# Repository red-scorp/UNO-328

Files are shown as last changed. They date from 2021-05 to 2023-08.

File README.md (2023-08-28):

# UNO/328 project

UNO/328 is a clone board of popular Arduino Uno board.
Main goal of the project is to improve EMC property of original board keeping it still simple and cheap to produce.

## Uno_v1.0

**Uno_v1.0** is version 1.0 of the board featuring CH340G USB to UART chip and ATMEGA328P as MCU.

Preview:

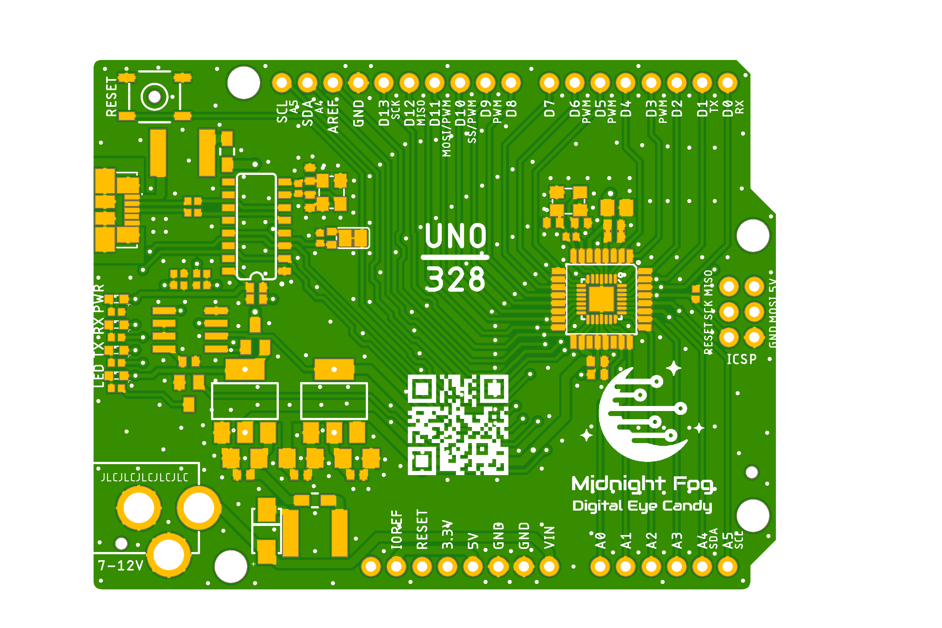
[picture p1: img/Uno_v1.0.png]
Uno_v1.0 preview


[Schematics in PDF format](doc/Uno_v1.0.pdf)

Features:

- Uno compatible board pinout
- Uno compatible MCU ATMEGA328P
- 2 layer board design
- alternative footprints for MCU: TQFP and HVQFN
- CH340G chip as USB to UART bridge
- modern microUSB connector
- possibly better EMC parameters (not yet tested)

CAM files are available.
BoM and PnP files for JLCPCB are available.

## Links

- CH340G Driver for Windows: [CH341SER_ZIP](http://www.wch.cn/download/CH341SER_ZIP.html)

## How to help

Your contributions as code, resources, or finances are welcome! Please contact me directly via email at andriy.golovnya@gmail.com or through my [GitHub profile](https://github.com/red-scorp).

If you'd like to make a financial contribution, you can donate via [PayPal](http://paypal.me/redscorp) or [Ko-Fi](http://ko-fi.com/redscorp). Your support is greatly appreciated.

Thanks in advance!

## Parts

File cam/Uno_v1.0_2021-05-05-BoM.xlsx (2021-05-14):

Qty | Designator | Footprint | Comment | LCSC Part # | Description
3 | C1, C2, C3 | 1206 | 47uF | C96123 (https://lcsc.com/product-detail/Multilayer-Ceramic-Capacitors-MLCC-SMD-SMT_SAMSUNG_CL31A476MPHNNNE_47uF-476-20-10V_C96123.html/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) | CAPACITOR, European symbol
1 | C17 | 0805 | 10uF | C15850 (https://lcsc.com/product-detail/Multilayer-Ceramic-Capacitors-MLCC-SMD-SMT_SAMSUNG_CL21A106KAYNNNE_10uF-106-10-25V_C15850.html/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) | CAPACITOR, European symbol
11 | C4, C5, C6, C7, C8, C11, C14, C15, C16, C18, C19 | 0402 | 100nF | C1525 (https://lcsc.com/product-detail/Multilayer-Ceramic-Capacitors-MLCC-SMD-SMT_SAMSUNG_CL05B104KO5NNNC_100nF-104-10-16V_C1525.html/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) | CAPACITOR, European symbol
4 | C9, C10, C12, C13 | 0402 | 12pF | C1547 (https://lcsc.com/product-detail/Multilayer-Ceramic-Capacitors-MLCC-SMD-SMT_12pF-120-5-50V_C1547.html/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) | CAPACITOR, European symbol
1 | D1 | SMA,DO-214AC | M7 | C366566 (https://lcsc.com/product-detail/Others_DOWO-M7_C366566.html/?href=jlc-SMT) | WE-TVSP Power TVS Diode
2 | F1, F2 | 1812 | 1812L050/30PR | C151168 (https://lcsc.com/product-detail/PTC-Resettable-Fuses_Littelfuse-1812L050-30PR_C151168.html/?href=jlc-SMT) | MF-SMDF Series - PRC Resettable Fuses
1 | IC1 | SOT-223 | AMS1117-5.0 | C6187 (https://lcsc.com/product-detail/Low-Dropout-Regulators-LDO_AMS_AMS1117-5-0_AMS1117-5-0_C6187.html/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) | Low drop fixed and adjustable positive voltage regulators 1 A
1 | IC2 | SOT-223 | AMS1117-3.3 | C6186 (https://lcsc.com/product-detail/Low-Dropout-Regulators-LDO_AMS_AMS1117-3-3_AMS1117-3-3_C6186.html/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) | Low drop fixed and adjustable positive voltage regulators 1 A
1 | IC3 | SOIC-8_3.9x4.9x1.27P | LM358DR2G | C7950 (https://lcsc.com/product-detail/General-Purpose-Amplifiers_ON-Semicon_LM358DR2G_ON-Semicon-ON-LM358DR2G_C7950.html/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) | OpAmp
2 | L1, L2 | 0805 | GZ2012D601TF | C1017 (https://lcsc.com/product-detail/Beads_Sunlord-GZ2012D601TF_C1017.html/?href=jlc-SMT) | WE-CBA SMD EMI Suppression Ferrite Bead
1 | LED1 | LED_0603 | GREEN | C72043 (https://lcsc.com/product-detail/Light-Emitting-Diodes-LED_0603-Green-light_C72043.html/?href=jlc-SMT) | LED
2 | LED2, LED3 | LED_0603 | BLUE | C72041 (https://lcsc.com/product-detail/Light-Emitting-Diodes-LED_0603-Blue-light_C72041.html/?href=jlc-SMT) | LED
1 | LED4 | LED_0603 | YELLOW | C72038 (https://lcsc.com/product-detail/Light-Emitting-Diodes-LED_0603-Yellow-light_C72038.html/?href=jlc-SMT) | LED
1 | Q1 | SMD-3225_4P | 12MHz | C9002 (https://lcsc.com/product-detail/SMD-Crystal-Resonators_Yangxing-Tech-X322512MSB4SI_C9002.html/?href=jlc-SMT) | Quartz Crystals (MHz) SMD:
1 | Q2 | SMD-3225_4P | 16MHz | C13738 (https://lcsc.com/product-detail/SMD-Crystal-Resonators_Yangxing-Tech-X322516MLB4SI_C13738.html/?href=jlc-SMT) | Quartz Crystals (MHz) SMD:
2 | R1, R2 | 0402 | 22R | C25092 (https://lcsc.com/product-detail/Chip-Resistor-Surface-Mount_Uniroyal-Elec-0402WGF220JTCE_C25092.html/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) | RESISTOR, European symbol
1 | R12 | 0402 | 10K | C25744 (https://lcsc.com/product-detail/Chip-Resistor-Surface-Mount_Uniroyal-Elec-0402WGF1002TCE_C25744.html/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) | RESISTOR, European symbol
2 | R3, R6 | 0402 | 1M | C26083 (https://lcsc.com/product-detail/Chip-Resistor-Surface-Mount_Uniroyal-Elec-0402WGF1004TCE_C26083.html/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) | RESISTOR, European symbol
4 | R4, R5, R13, R14 | 0402 | 100K | C25741 (https://lcsc.com/product-detail/Chip-Resistor-Surface-Mount_Uniroyal-Elec-0402WGF1003TCE_C25741.html/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) | RESISTOR, European symbol
5 | R7, R8, R9, R10, R11 | 0402 | 1K | C11702 (https://lcsc.com/product-detail/Chip-Resistor-Surface-Mount_Uniroyal-Elec-0402WGF1001TCE_C11702.html/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) | RESISTOR, European symbol
1 | T1 | SOT-23-3L | AO3401A | C15127 | P-Channel MOSFET - Generic
1 | T2 | SOT-23-3 | 2N7002 | C8545 (https://lcsc.com/product-detail/MOSFET_Changjiang-Electronics-Tech-CJ-2N7002_C8545.html/?href=jlc-SMT) | N-Channel MOSFET - Generic
1 | U1 | SOIC-16_3.9x9.9x1.27P | CH340G | C14267 (https://lcsc.com/product-detail/USB_CH340G_C14267.html/?href=jlc-SMT) | A simple USB 2.0 to Serial IC.
1 | U2 | TQFP-32_7.0x7.0x0.8P | ATMEGA328P-AU | C14877 (https://lcsc.com/product-detail/ATMEL-AVR_ATMEL_ATMEGA328P-AU_ATMEGA328P-AU_C14877.html/?href=jlc-SMT) | Popular 328P in QFP

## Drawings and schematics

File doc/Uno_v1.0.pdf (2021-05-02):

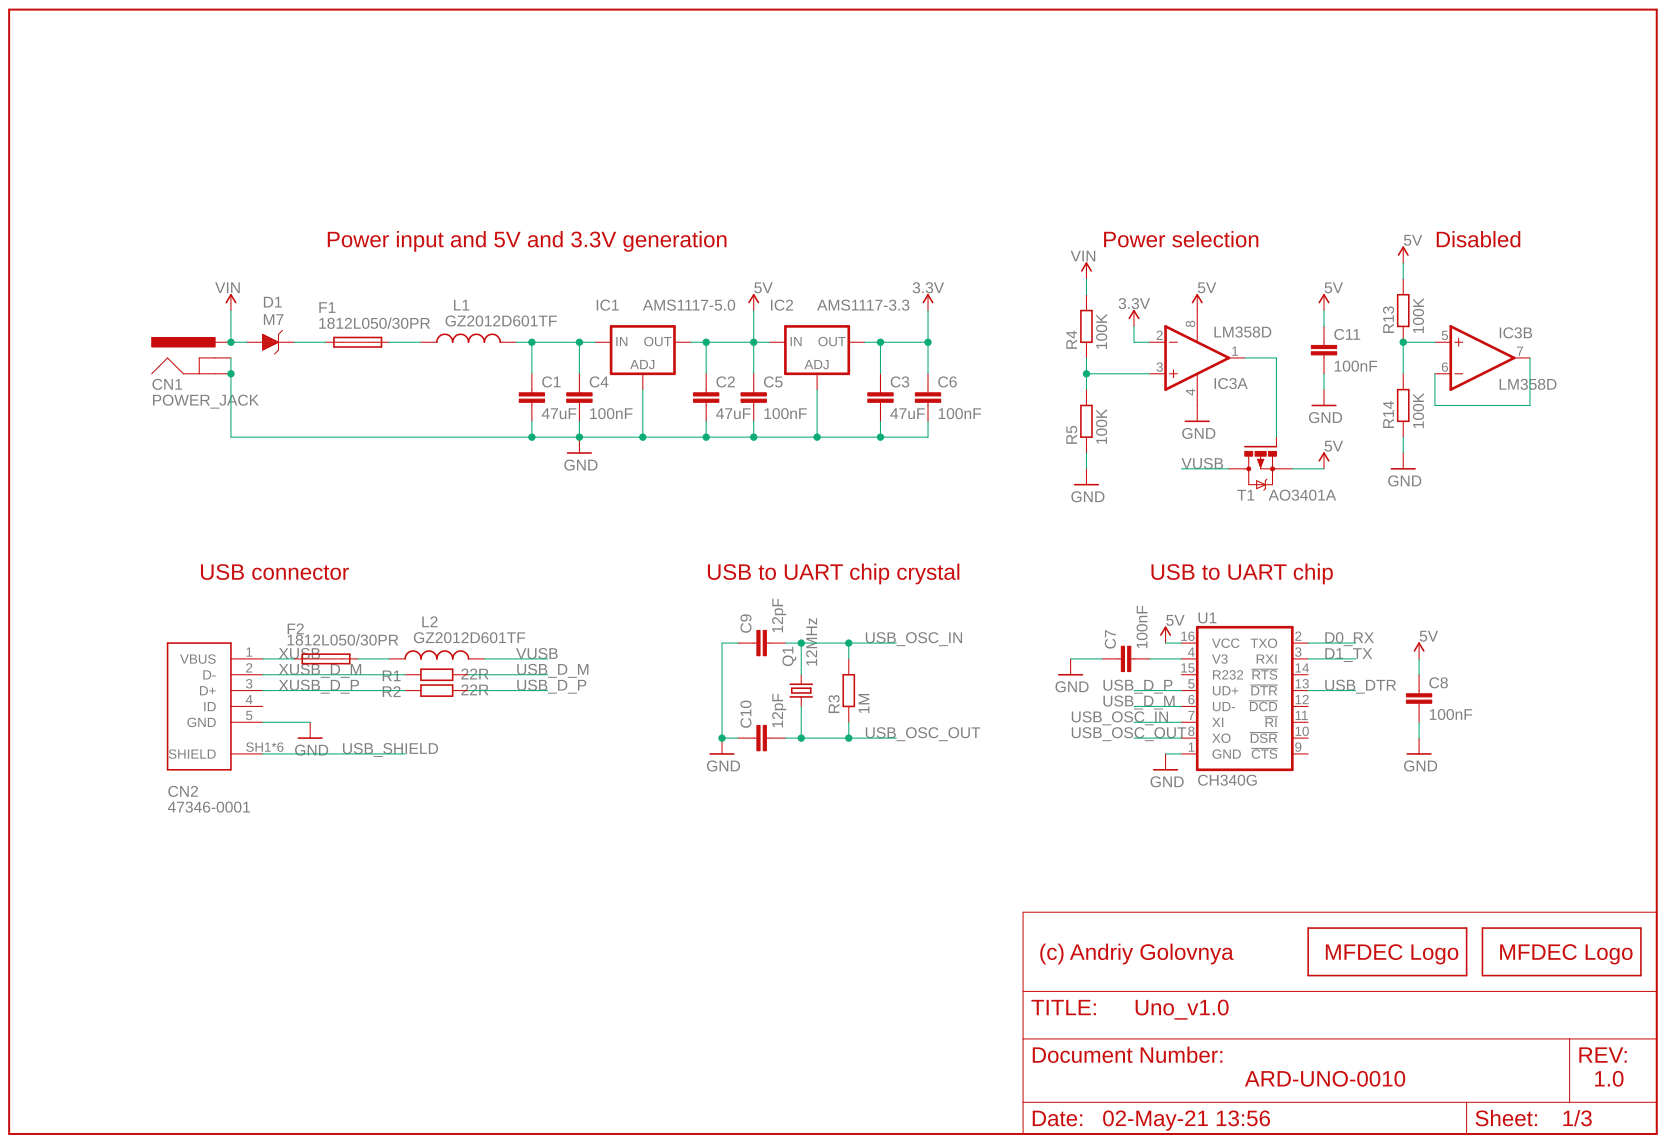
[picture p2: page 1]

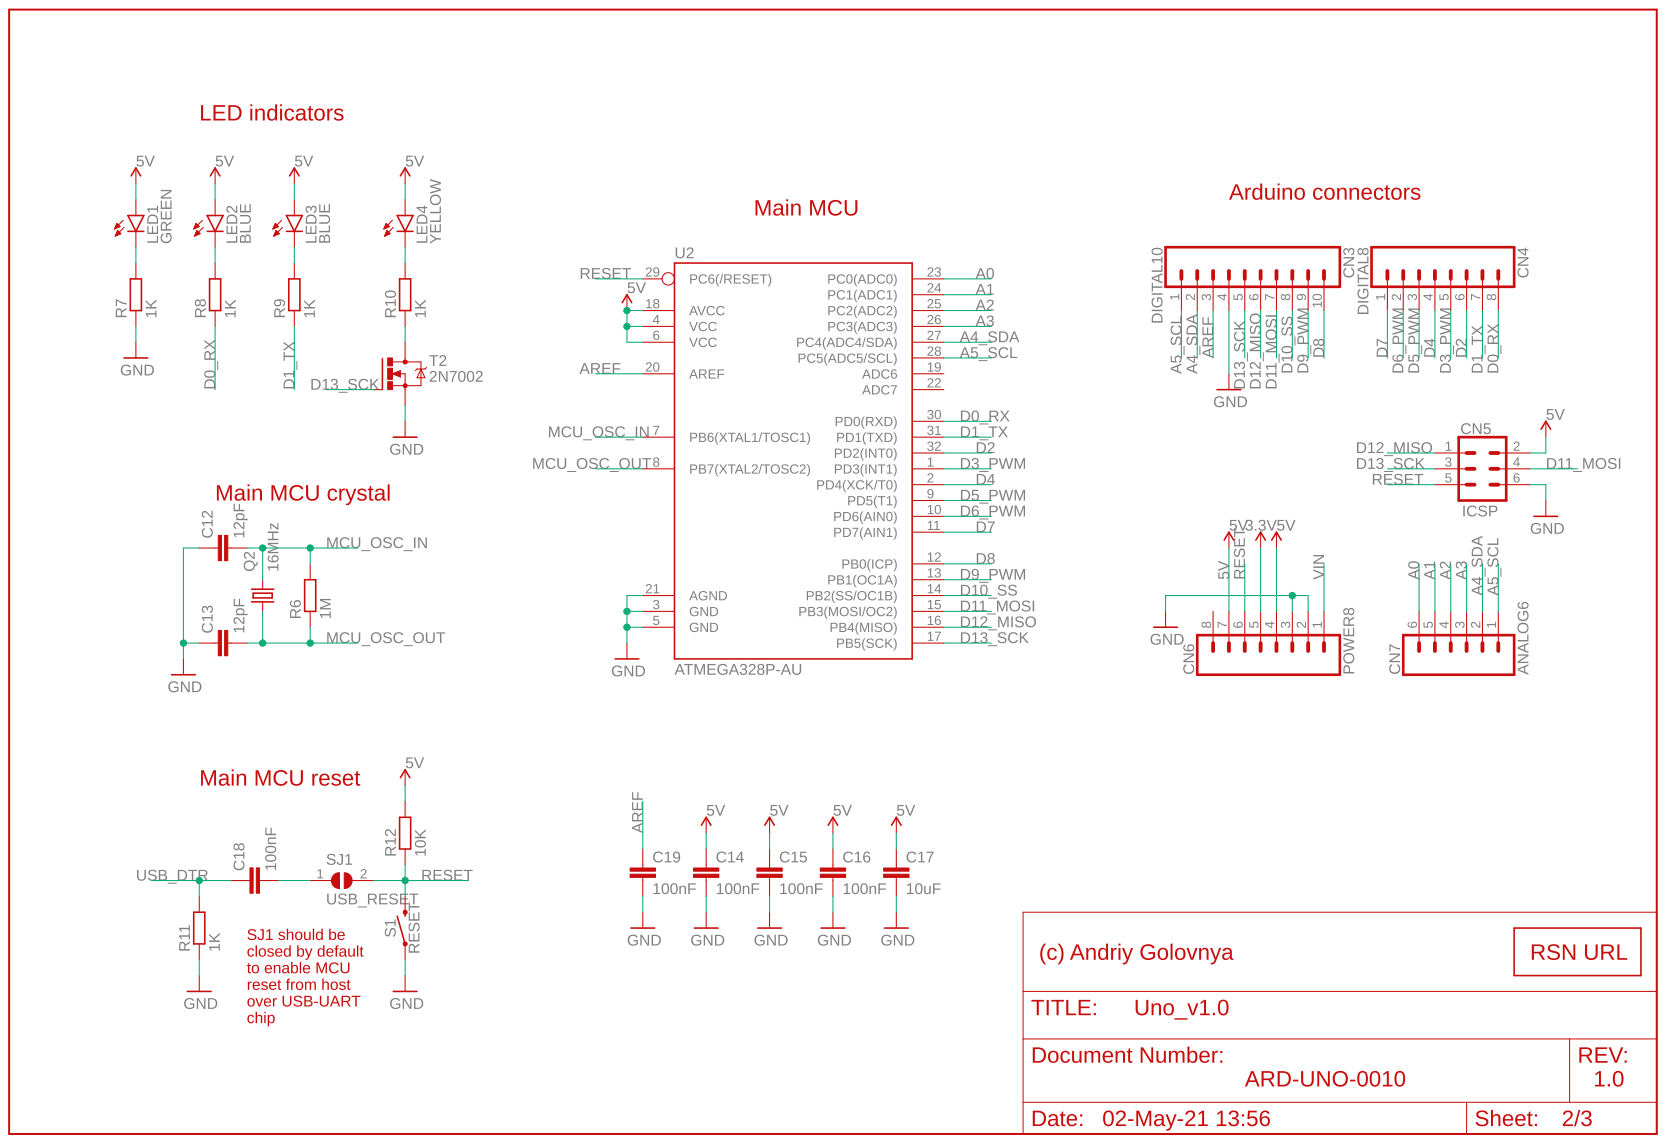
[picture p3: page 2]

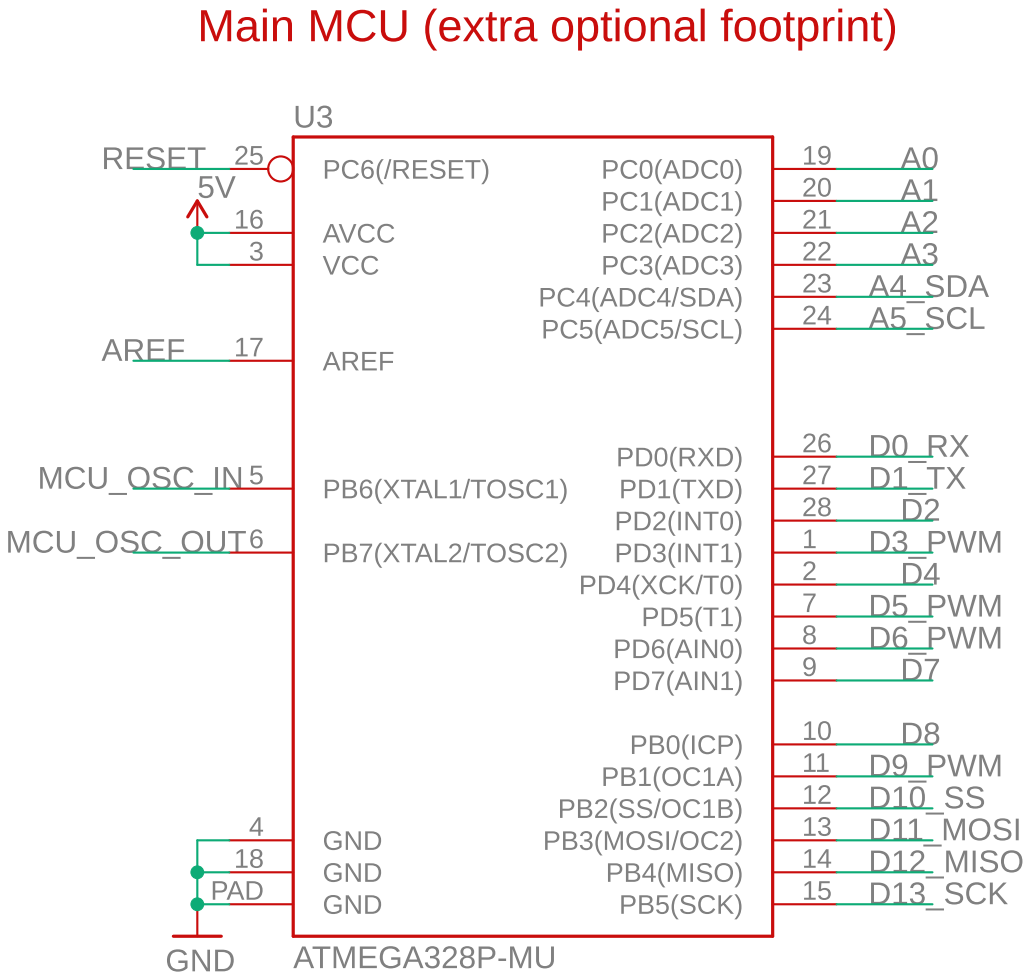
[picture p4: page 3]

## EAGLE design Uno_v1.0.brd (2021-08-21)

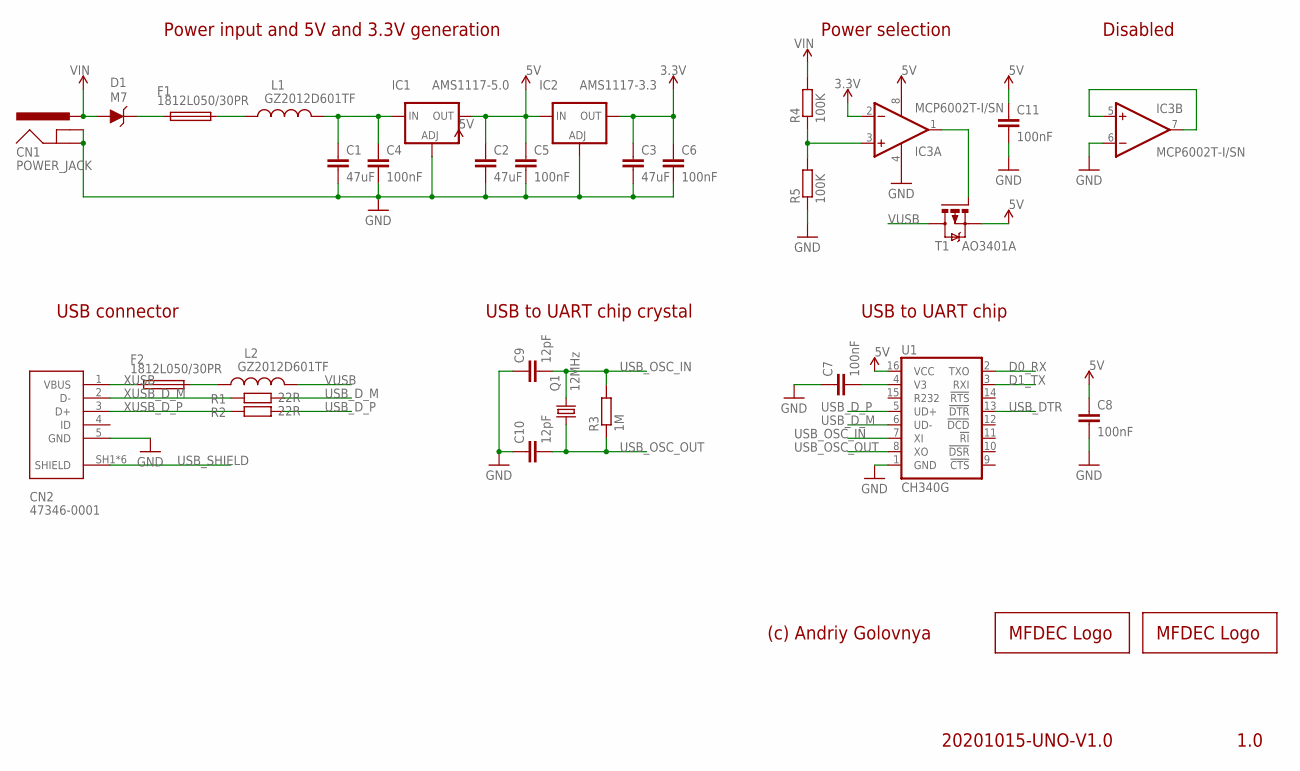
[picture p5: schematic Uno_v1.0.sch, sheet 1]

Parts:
C1, C2, C3: 47uF; C1206
C4, C5, C6, C7, C8, C11: 100nF; C0402
C9, C10: 12pF; C0402
CN1: POWER_JACK; POWER_JACK_PTH
CN2: 47346-0001; MOLEX_47346-0001
D1: M7; WE-TVSP_DO-214AC_UNIDIRECTIONAL
F1, F2: 1812L050/30PR; MF-SMDF050
IC1: AMS1117-5.0; SOT223
IC2: AMS1117-3.3; SOT223
IC3: MCP6002T-I/SN; SO08
L1, L2: GZ2012D601TF; WE-CBA_0805(W=4)
LOGO1: MFDECLOGO_SQ_10MM; MFDEC_SQ_10MM
LOGO2: MFDECLOGO_L_40MM; MFDEC_L_40MM
Q1: 12MHz; 3.2X2.5_KX-7
R1, R2: 22R; R0402
R3: 1M; R0402
R4, R5: 100K; R0402
T1: AO3401A; SOT23
U1: CH340G; SO016

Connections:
3.3V: C3.1, C6.1, IC2.4 (OUT), IC3.2 (-IN); also elsewhere on the board
5V: C2.1, C5.1, C8.1, C11.1, IC1.4 (OUT), IC2.3 (IN), IC3.8 (V+), T1.2 (S), U1.16 (VCC); also elsewhere on the board
D0_RX: U1.2 (TXO); also elsewhere on the board
D1_TX: U1.3 (RXI); also elsewhere on the board
unnamed: D1.1 (C), F1.1
unnamed: F1.2, L1.1
unnamed: F2.2, L2.1
unnamed: C7.2, U1.4 (V3)
unnamed: IC3.1 (OUT), T1.1 (G)
unnamed: IC3.3 (+IN), R4.1, R5.2
unnamed: C1.1, C4.1, IC1.3 (IN), L1.2
USB_DTR: U1.13 (!DTR); also elsewhere on the board
USB_D_M: R1.2, U1.6 (UD-)
USB_D_P: R2.2, U1.5 (UD+)
USB_OSC_IN: C9.2, Q1.3 (2), R3.2, U1.7 (XI)
USB_OSC_OUT: C10.2, Q1.1, R3.1, U1.8 (XO)
USB_SHIELD: CN2.SH1 (SHIELD), CN2.SH2 (SHIELD), CN2.SH3 (SHIELD), CN2.SH4 (SHIELD), CN2.SH5 (SHIELD), CN2.SH6 (SHIELD)
VIN: CN1.PWR, D1.2 (A), R4.2; also elsewhere on the board
VUSB: L2.2, T1.3 (D)
XUSB: CN2.1 (VBUS), F2.1
XUSB_D_M: CN2.2 (D-), R1.1
XUSB_D_P: CN2.3 (D+), R2.1

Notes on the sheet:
1.0
(c) Andriy Golovnya
20201015-UNO-V1.0
Power input and 5V and 3.3V generation
USB connector
USB to UART chip
USB to UART chip crystal
Power selection
Disabled

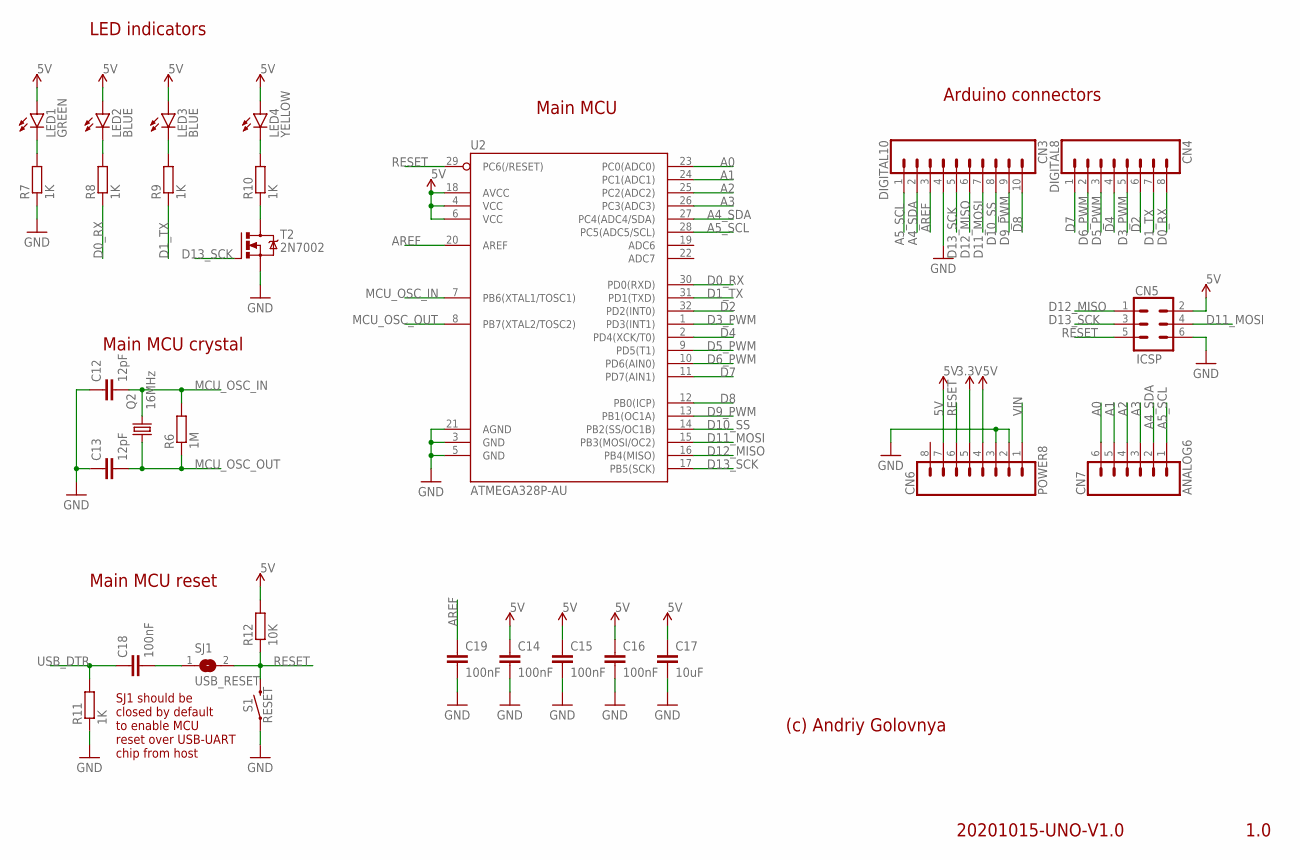
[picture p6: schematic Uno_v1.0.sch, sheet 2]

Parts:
C12, C13: 12pF; C0402
C14, C15, C16, C18, C19: 100nF; C0402
C17: 10uF; C0805
CN3: DIGITAL10; 1X10_NO_SILK
CN4: DIGITAL8; 1X08_NO_SILK
CN5: ICSP; 2X3-NS
CN6: POWER8; 1X08_NO_SILK
CN7: ANALOG6; 1X06_NO_SILK
LED1: GREEN; SML0603
LED2, LED3: BLUE; SML0603
LED4: YELLOW; SML0603
Q2: 16MHz; 3.2X2.5_KX-7
R6: 1M; R0402
R7, R8, R9, R10, R11: 1K; R0402
R12: 10K; R0402
S1: RESET; TACTILE_SWITCH_SMD_5.2MM
SJ1: USB_RESET; SJ
T2: 2N7002; SOT23
U2: ATMEGA328P-AU; TQFP32-08

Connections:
3.3V: CN6.5; also elsewhere on the board
5V: C14.1, C15.1, C16.1, C17.1, CN5.2, CN6.4, CN6.7, LED1.A, LED2.A, LED3.A, LED4.A, R12.2, U2.4 (VCC), U2.6 (VCC), U2.18 (AVCC); also elsewhere on the board
A0: CN7.6, U2.23 (PC0(ADC0)); also elsewhere on the board
A1: CN7.5, U2.24 (PC1(ADC1)); also elsewhere on the board
A2: CN7.4, U2.25 (PC2(ADC2)); also elsewhere on the board
A3: CN7.3, U2.26 (PC3(ADC3)); also elsewhere on the board
A4_SDA: CN3.2, CN7.2, U2.27 (PC4(ADC4/SDA)); also elsewhere on the board
A5_SCL: CN3.1, CN7.1, U2.28 (PC5(ADC5/SCL)); also elsewhere on the board
AREF: C19.1, CN3.3, U2.20 (AREF); also elsewhere on the board
D0_RX: CN4.8, R8.1, U2.30 (PD0(RXD)); also elsewhere on the board
D1_TX: CN4.7, R9.1, U2.31 (PD1(TXD)); also elsewhere on the board
D2: CN4.6, U2.32 (PD2(INT0)); also elsewhere on the board
D3_PWM: CN4.5, U2.1 (PD3(INT1)); also elsewhere on the board
D4: CN4.4, U2.2 (PD4(XCK/T0)); also elsewhere on the board
D5_PWM: CN4.3, U2.9 (PD5(T1)); also elsewhere on the board
D6_PWM: CN4.2, U2.10 (PD6(AIN0)); also elsewhere on the board
D7: CN4.1, U2.11 (PD7(AIN1)); also elsewhere on the board
D8: CN3.10, U2.12 (PB0(ICP)); also elsewhere on the board
D9_PWM: CN3.9, U2.13 (PB1(OC1A)); also elsewhere on the board
D10_SS: CN3.8, U2.14 (PB2(SS/OC1B)); also elsewhere on the board
D11_MOSI: CN3.7, CN5.4, U2.15 (PB3(MOSI/OC2)); also elsewhere on the board
D12_MISO: CN3.6, CN5.1, U2.16 (PB4(MISO)); also elsewhere on the board
D13_SCK: CN3.5, CN5.3, T2.1 (G), U2.17 (PB5(SCK)); also elsewhere on the board
MCU_OSC_IN: C12.2, Q2.3 (2), R6.2, U2.7 (PB6(XTAL1/TOSC1)); also elsewhere on the board
MCU_OSC_OUT: C13.2, Q2.1, R6.1, U2.8 (PB7(XTAL2/TOSC2)); also elsewhere on the board
unnamed: C18.2, SJ1.1
unnamed: LED1.C, R7.2
unnamed: LED3.C, R9.2
unnamed: LED2.C, R8.2
unnamed: LED4.C, R10.2
unnamed: R10.1, T2.3 (D)
RESET: CN5.5, CN6.6, R12.1, S1.3 (2), SJ1.2, U2.29 (PC6(/RESET)); also elsewhere on the board
USB_DTR: C18.1, R11.2; also elsewhere on the board
VIN: CN6.1; also elsewhere on the board

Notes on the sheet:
1.0
(c) Andriy Golovnya
20201015-UNO-V1.0
LED indicators
Main MCU
Main MCU reset
Arduino connectors
Main MCU crystal
SJ1 should be closed by default to enable MCU reset over USB-UART chip from host

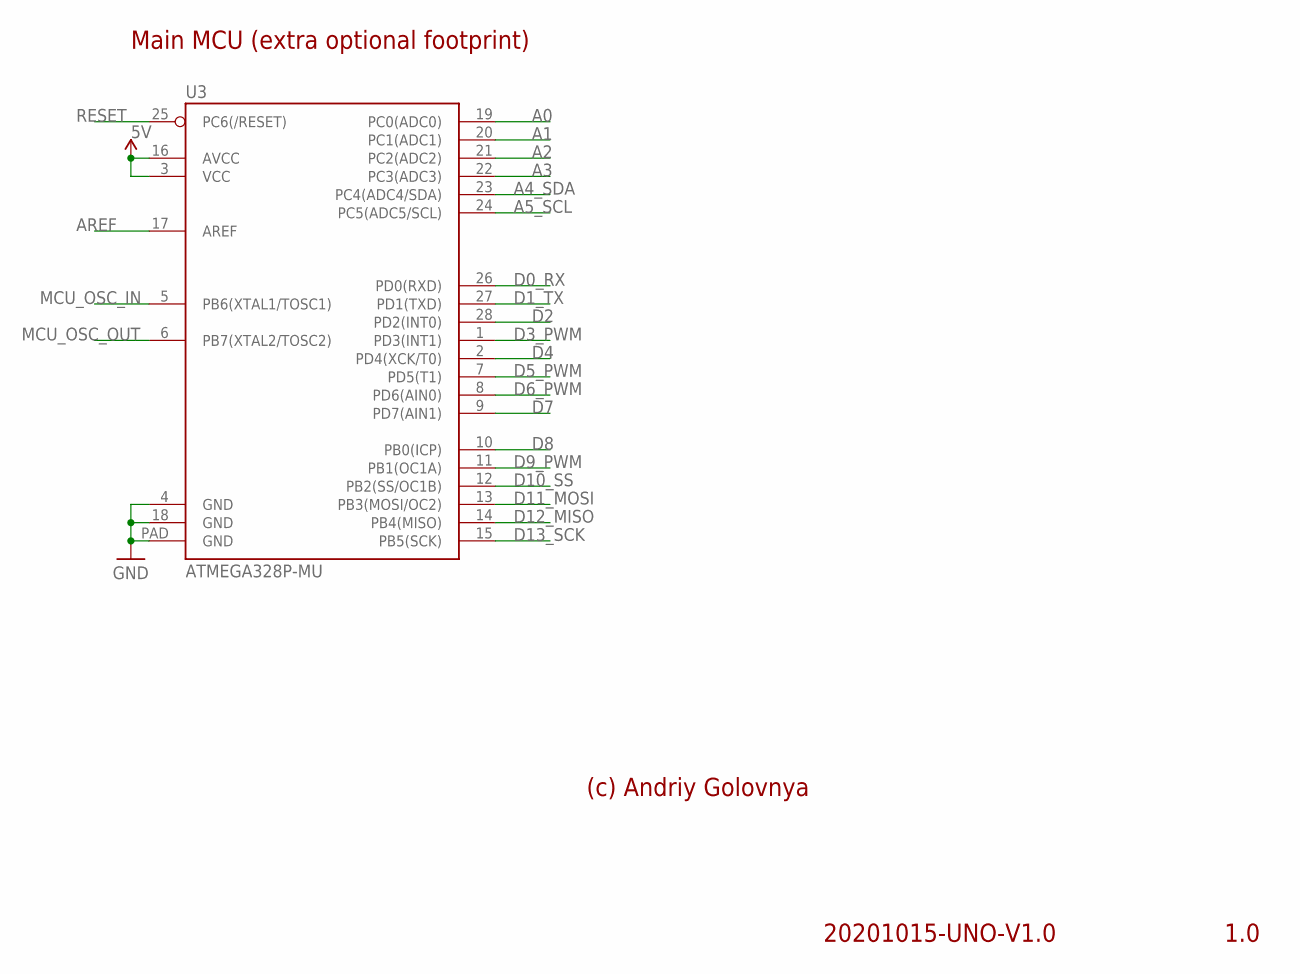
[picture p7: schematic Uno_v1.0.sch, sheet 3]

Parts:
U3: ATMEGA328P-MU; VQFN-28

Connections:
5V: U3.3 (VCC), U3.16 (AVCC); also elsewhere on the board
A0: U3.19 (PC0(ADC0)); also elsewhere on the board
A1: U3.20 (PC1(ADC1)); also elsewhere on the board
A2: U3.21 (PC2(ADC2)); also elsewhere on the board
A3: U3.22 (PC3(ADC3)); also elsewhere on the board
A4_SDA: U3.23 (PC4(ADC4/SDA)); also elsewhere on the board
A5_SCL: U3.24 (PC5(ADC5/SCL)); also elsewhere on the board
AREF: U3.17 (AREF); also elsewhere on the board
D0_RX: U3.26 (PD0(RXD)); also elsewhere on the board
D1_TX: U3.27 (PD1(TXD)); also elsewhere on the board
D2: U3.28 (PD2(INT0)); also elsewhere on the board
D3_PWM: U3.1 (PD3(INT1)); also elsewhere on the board
D4: U3.2 (PD4(XCK/T0)); also elsewhere on the board
D5_PWM: U3.7 (PD5(T1)); also elsewhere on the board
D6_PWM: U3.8 (PD6(AIN0)); also elsewhere on the board
D7: U3.9 (PD7(AIN1)); also elsewhere on the board
D8: U3.10 (PB0(ICP)); also elsewhere on the board
D9_PWM: U3.11 (PB1(OC1A)); also elsewhere on the board
D10_SS: U3.12 (PB2(SS/OC1B)); also elsewhere on the board
D11_MOSI: U3.13 (PB3(MOSI/OC2)); also elsewhere on the board
D12_MISO: U3.14 (PB4(MISO)); also elsewhere on the board
D13_SCK: U3.15 (PB5(SCK)); also elsewhere on the board
MCU_OSC_IN: U3.5 (PB6(XTAL1/TOSC1)); also elsewhere on the board
MCU_OSC_OUT: U3.6 (PB7(XTAL2/TOSC2)); also elsewhere on the board
RESET: U3.25 (PC6(/RESET)); also elsewhere on the board

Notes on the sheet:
1.0
(c) Andriy Golovnya
20201015-UNO-V1.0
Main MCU (extra optional footprint)

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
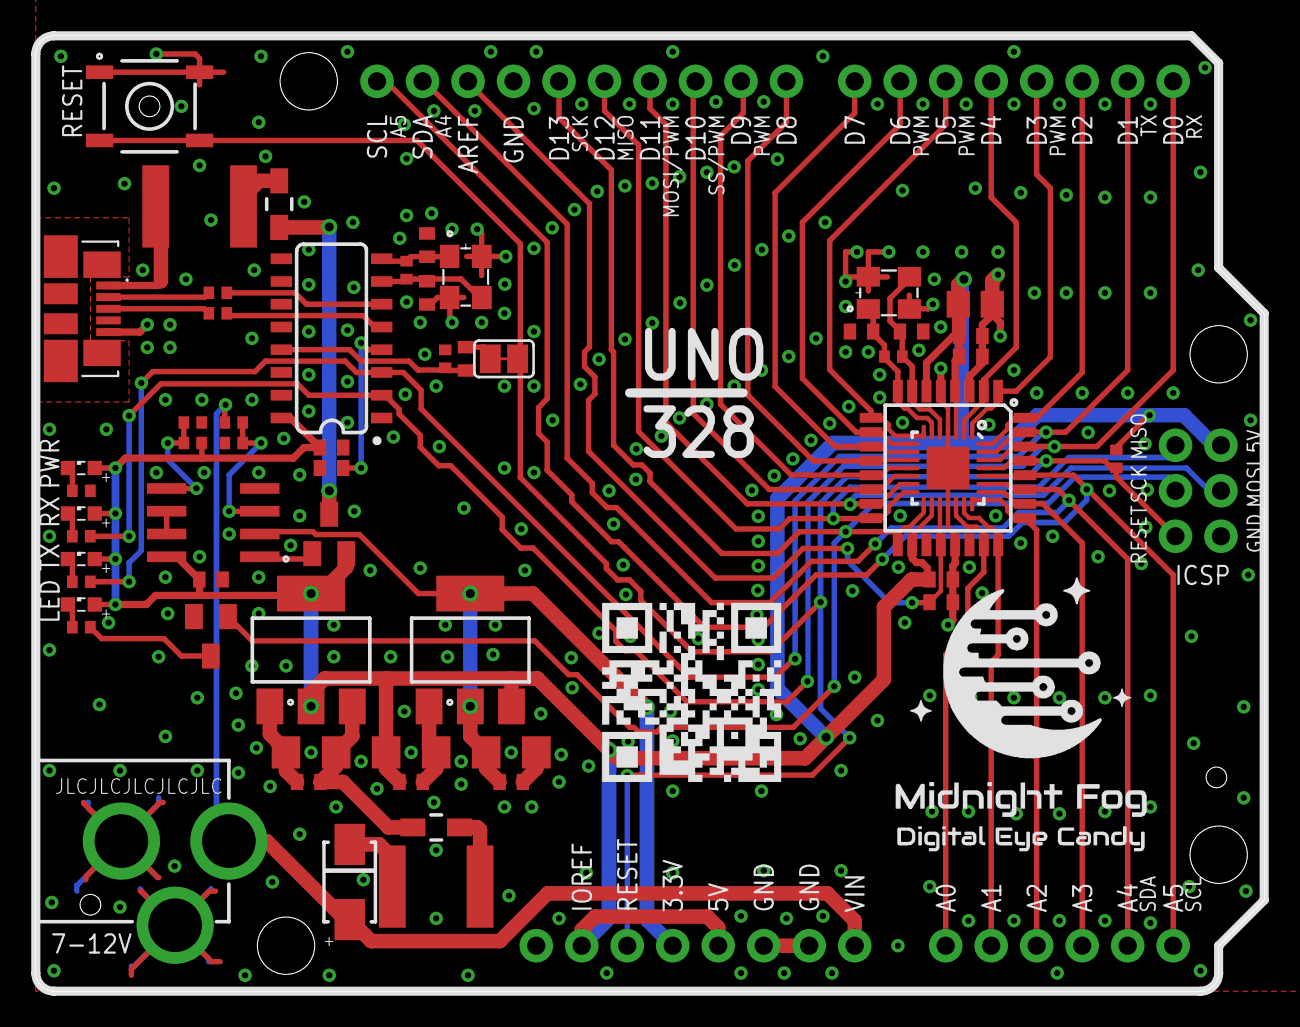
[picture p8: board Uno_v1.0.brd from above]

Board: 2 copper layers, 68.6 x 53.3 mm, 67 parts (1 on the bottom side), 53 nets.

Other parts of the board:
HOLE1, HOLE2, HOLE3: TOOLINGHOLE; TOOLING-HOLE
LOGO3: RSNURL_QR_10MM
R13, R14: 100K; R0402

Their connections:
5V: R13.2; also elsewhere on the board

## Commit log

2020-10-17 First commit in Uno repo
    [Uno_v1.0.brd, Uno_v1.0.sch]
2020-10-17 Add some traces
    [Uno_v1.0.brd, Uno_v1.0.sch]
2020-10-18 Add some wires. Add top/bottom fills. Add top/bottom silks. Add pin descriptions.
    [Uno_v1.0.brd, Uno_v1.0.sch]
2020-10-18 Minor adjustments
    [Uno_v1.0.brd, Uno_v1.0.sch]
2020-10-19 Fix connection of V3 pin of CH340G
    [Uno_v1.0.brd, Uno_v1.0.sch]
2020-10-23 Change capacitor sizes. Move stuff around.
    [Uno_v1.0.brd, Uno_v1.0.sch]
2020-10-24 Move stuff around. Change how SJ1 is closed by default. Add ground connections to Q2 and reset button.
    [Uno_v1.0.brd, Uno_v1.0.sch]
2020-10-27 Add second footprint for atmega328. Move components a little.
    [Uno_v1.0.brd, Uno_v1.0.sch]
2020-10-27 Rotated CH340G 180 degrees. Moved stuff around a little.
    [Uno_v1.0.brd]
2020-10-29 Move some stuff around
    [Uno_v1.0.brd]
2020-10-30 Move stuff around
    [Uno_v1.0.brd]
2020-10-30 Move stuff around.
    [Uno_v1.0.brd]
2020-10-30 Add RSN URL to the board. Moved DTR-reset group closed to CH340G.
    [Uno_v1.0.brd]
2020-11-01 Added CAM, BOM and PaP files for JLCPCB. Move some stuff around.
    [Uno_v1.0.brd, Uno_v1.0_2020-11-01-BOM.xlsx, Uno_v1.0_2020-11-01-PaP.xlsx]
2020-11-02 Fix MOSI label. Moved UNO logo a little.
    [Uno_v1.0.brd]
2020-11-04 Added extra pin descriptions. Moved UNO logo up a bit. Generated new CAM.
    [Uno_v1.0.brd]
2020-11-13 Add extra fancy connections around power jack ground
    [Uno_v1.0.brd]
2020-12-05 Changed some traces. Moved few components a little.
    [Uno_v1.0.brd]
2020-12-05 Generated new CAM and PaP. BOM remains the same.
    [Uno_v1.0_2020-11-01-PaP.xlsx, Uno_v1.0_2020-12-05-PaP.xlsx]
2020-12-06 Moved few vias.
    [Uno_v1.0.brd]
2020-12-06 Added white frame around the board.
    [Uno_v1.0.brd]
2021-01-16 tried to fix BOM and PaP for JLCPCB
    [Uno_v1.0_2020-11-01-BOM.xlsx, Uno_v1.0_2020-12-05-PaP.xlsx]
2021-04-12 Moved main MCU a little bit to the right. Generated new CAM. Generated new preview.
    [Uno_v1.0.brd, Uno_v1.0_2020-11-01-BOM.xlsx, Uno_v1.0_2020-12-05-PaP.xlsx]
2021-04-12 Restored old BOM. Generated new PnP.
    [Uno_v1.0_2020-11-01-BOM.xlsx, Uno_v1.0_2021-04-12-PnP.xlsx]
2021-04-12 Moved some wires. Generated new CAM. Generated new preview.
    [Uno_v1.0.brd]
2021-04-13 Use LM358D OpAmp instead. Generated new CAM. Generated new PNG preview. Generated new PDF schematic.
    [Uno_v1.0.brd, Uno_v1.0_2020-11-01-BOM.xlsx, Uno_v1.0_2021-04-13-BOM.xlsx]
2021-04-14 Properly disabled second channel of op amp. Generated new CAM files. Generated new PNG preview. Generated new PDF schematics. Generated new BoM and PnP files.
    [Uno_v1.0.brd, Uno_v1.0_2021-04-12-PnP.xlsx, Uno_v1.0_2021-04-13-BOM.xlsx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]
2021-04-14 Fixed unconnected symbol on schematics. Generated new PDF schematics. Fixed BoM and PnP files for JLCPB assembly.
    [Uno_v1.0_2021-04-14-BoM.xlsx, Uno_v1.0_2021-04-14-PnP.xlsx]
2021-05-02 Redone chip wiring for better reverse currents.
    [Uno_v1.0.brd]
2021-05-02 Generated PDF schematics. Generated PNG preview.
2021-05-02 Generated BoM and PnP files.
    [Uno_v1.0_2021-04-14-BoM.xlsx, Uno_v1.0_2021-04-14-PnP.xlsx, Uno_v1.0_2021-05-02-BoM.xlsx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]
2021-05-03 Moved some traces around.
    [Uno_v1.0.brd]
2021-05-05 Generate CAM files. Updated BoM file.
    [Uno_v1.0_2021-05-02-BoM.xlsx, Uno_v1.0_2021-05-05-BoM.xlsx]
2021-05-06 Added JLCPCB tooling holes and order number placement.
    [Uno_v1.0.brd]
2021-05-14 Changed few components to do manufacturing possible.
    [Uno_v1.0_2021-05-02-PnP.xlsx, Uno_v1.0_2021-05-05-BoM.xlsx]
2021-08-21 Made secondary texts bigger. Generated CAM files. Generated PNG preview.
    [Uno_v1.0.brd]

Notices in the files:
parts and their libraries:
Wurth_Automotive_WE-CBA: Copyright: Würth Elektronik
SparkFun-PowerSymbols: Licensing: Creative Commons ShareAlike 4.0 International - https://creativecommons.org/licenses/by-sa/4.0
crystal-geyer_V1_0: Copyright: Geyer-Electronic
